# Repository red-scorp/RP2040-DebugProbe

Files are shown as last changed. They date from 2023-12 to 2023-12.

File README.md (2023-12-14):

```
____________  _____  _____    ___ _____                
| ___ \ ___ \/ __  \|  _  |  /   |  _  |               
| |_/ / |_/ /`' / /'| |/' | / /| | |/' |               
|    /|  __/   / /  |  /| |/ /_| |  /| |               
| |\ \| |    ./ /___\ |_/ /\___  \ |_/ /               
\_| \_\_|    \_____/ \___/     |_/\___/                
______     _                ______          _          
|  _  \   | |               | ___ \        | |         
| | | |___| |__  _   _  __ _| |_/ / __ ___ | |__   ___ 
| | | / _ \ '_ \| | | |/ _` |  __/ '__/ _ \| '_ \ / _ \
| |/ /  __/ |_) | |_| | (_| | |  | | | (_) | |_) |  __/
|___/ \___|_.__/ \__,_|\__, \_|  |_|  \___/|_.__/ \___|
                        __/ |                          
                       |___/                           
```

# RP2040-DebugProbe Project

The **RP2040-DebugProbe** project aims to re-imagine Raspberry Pi Debug Probe.

## RP2040-DebugProbe Board

The **RP2040-DebugProbe** board is a 4-layer design intended to accommodate the popular Raspberry Pi RP2040 MCU with all required component to function identically to Raspberry Pi Debug Probe.

This board features target JTAG connector and PC host USB Type-C connector. It also has a SWD connector and UART connector for the main MCU debugging. The board is pin-compatible with Raspberry Pi Debug Probe and can be used with the same picoprobe SW.

Preview:

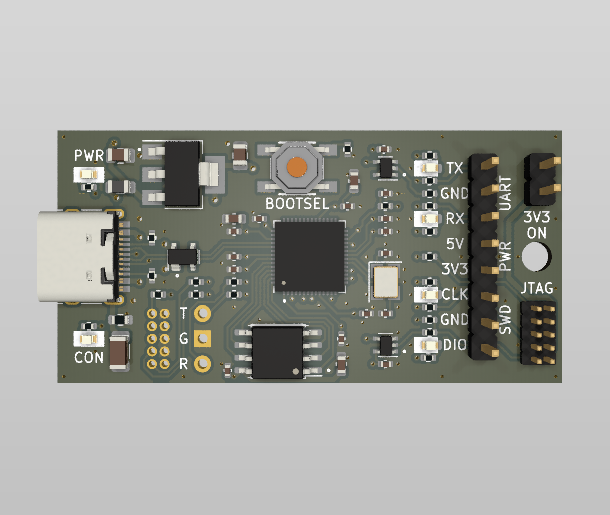
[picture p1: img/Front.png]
RP2040-DebugProbe Front preview

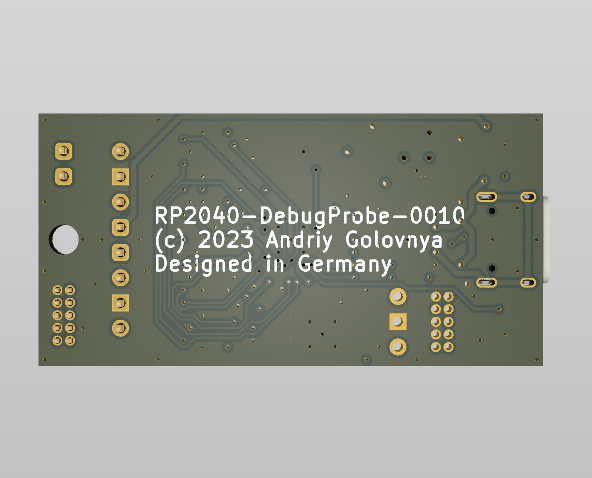
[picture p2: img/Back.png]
RP2040-DebugProbe Back preview

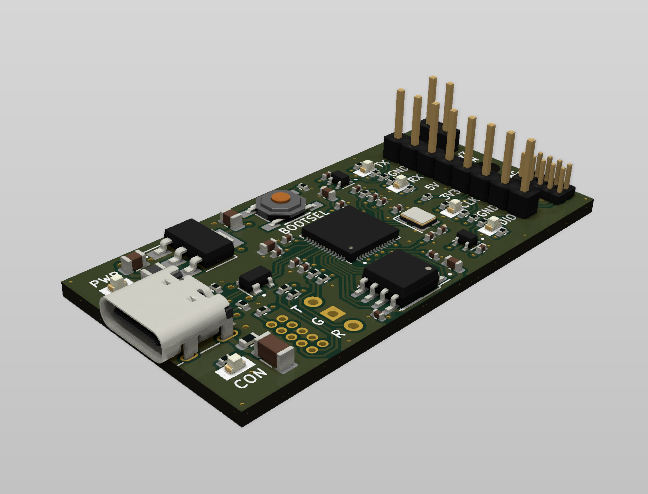
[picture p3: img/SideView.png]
RP2040-DebugProbe Side View preview


You can view the [Schematics in PDF format](doc/RP2040-DebugProbe.pdf) for detailed information.

STEP 3D file is available [with pins](doc/RP2040-DebugProbe.step).

Features:

- Very small form-factor of about 50x25mm (2x1in).
- Raspberry Pi RP2040 MCU as a heart of the board.
- 2x5 1.27mm JTAG connector for programming and debugging.
- 1x8 2.54mm SWD/UART/Power connector for programming and debugging.
- USB Type-C connector for power and communication.
- Several LEDs to indicate power and status.
- 2x5 1.27mm SWD connector and 1x3 2.54mm UART connector for main MCU debugging.
- BOOTSEL button to enter the bootloader mode for flashing new picoprobe SW.
- Pin-compatible with Raspberry Pi Debug Probe.
- Extra TARGET_RESET line connected to GPIO10 for target MCU reset over JTAG.

CAM files, as well as the BOM and CPL files for JLCPCB, are available.

## Version History

### v1.0b1

v1.0b1 board preview

Initial release for testing purposes.

## Links

- [Raspberry Pi RP2040 information page](https://www.raspberrypi.com/documentation/microcontrollers/rp2040.html).
- [Raspberry Pi Debug Probe information page](https://www.raspberrypi.com/documentation/microcontrollers/debug-probe.html).
- [Picoprobe SW for the board](https://github.com/raspberrypi/picoprobe).

## How to Help

Your contributions as code, resources, or finances are welcome! Please contact me directly via email at andriy.golovnya@gmail.com or through my [GitHub profile](https://github.com/red-scorp).

If you'd like to make a financial contribution, you can donate via [PayPal](http://paypal.me/redscorp) or [Ko-Fi](http://ko-fi.com/redscorp). Your support is greatly appreciated.

Thanks in advance!

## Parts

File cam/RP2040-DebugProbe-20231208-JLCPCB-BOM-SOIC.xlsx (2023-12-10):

Qty | Designator | Footprint | JLCPCB Part# | Comment
12 | R13,R19,R23,R15,R16,R22,R18,R17,R21,R9,R20,R14 | 0402 | C25076 | 100R
2 | D7,D4 | 0603 | C72038 | YELLOW
13 | C4,C11,C9,C3,C17,C7,C12,C13,C18,C2,C6,C10,C8 | 0402 | C1525 | 100nF
3 | C5,C1,C16 | 0603 | C1604 | 2.2uF
1 | FB2 | 0805 | C1015 | GZ2012D101TF
2 | U3,U6 | SC-70-5 | C2652100 | 74AUP1T17
2 | D2,D5 | 0603 | C2286 | RED
2 | R11,R10 | 0402 | C25905 | 5k1
1 | J1 | SMD,P=1.27mm | C2935953 | CONN_MCU_JTAG
2 | C20,C19 | 0402 | C1547 | 12pF
1 | U2 | LQFN-56(7x7) | C2040 | RP2040
7 | R3,R7,R5,R1,R6,R4,R2 | 0402 | C11702 | 1k
1 | J4 | Plugin,P=2.54mm | C2685154 | CONN_3V3_JUMPER
1 | C21 | 1206 | C106074 | 4.7nF 1kV
2 | C14,C15 | 0805 | C15850 | 10uF
1 | J7 | SMD,P=1.27mm | C2935953 | CONN_DBG_JTAG
1 | D3 | SOT-143 | C5158049 | PRTR5V0U2X
1 | SW1 | SMD | C318884 | TS-1187A-B-A-B
2 | D1,D6 | 0603 | C72043 | GREEN
1 | J10 | SMD | C2689844 | CONN_USB
1 | Y1 | SMD3225-4P | C9002 | 12MHz
1 | U1 | SOIC-8-208mil | C97521 | W25Q128JVS
1 | U5 | SOT-223 | C6187 | AMS1117-3.3
1 | J3 | Plugin,P=2.54mm | C6332201 | CONN_DBG_COMB
1 | J2 | Plugin,P=2.54mm | C429954 | CONN_MCU_UART
1 | R8 | 0402 | C25744 | 10k
1 | R12 | 0603 | C136593 | 1M

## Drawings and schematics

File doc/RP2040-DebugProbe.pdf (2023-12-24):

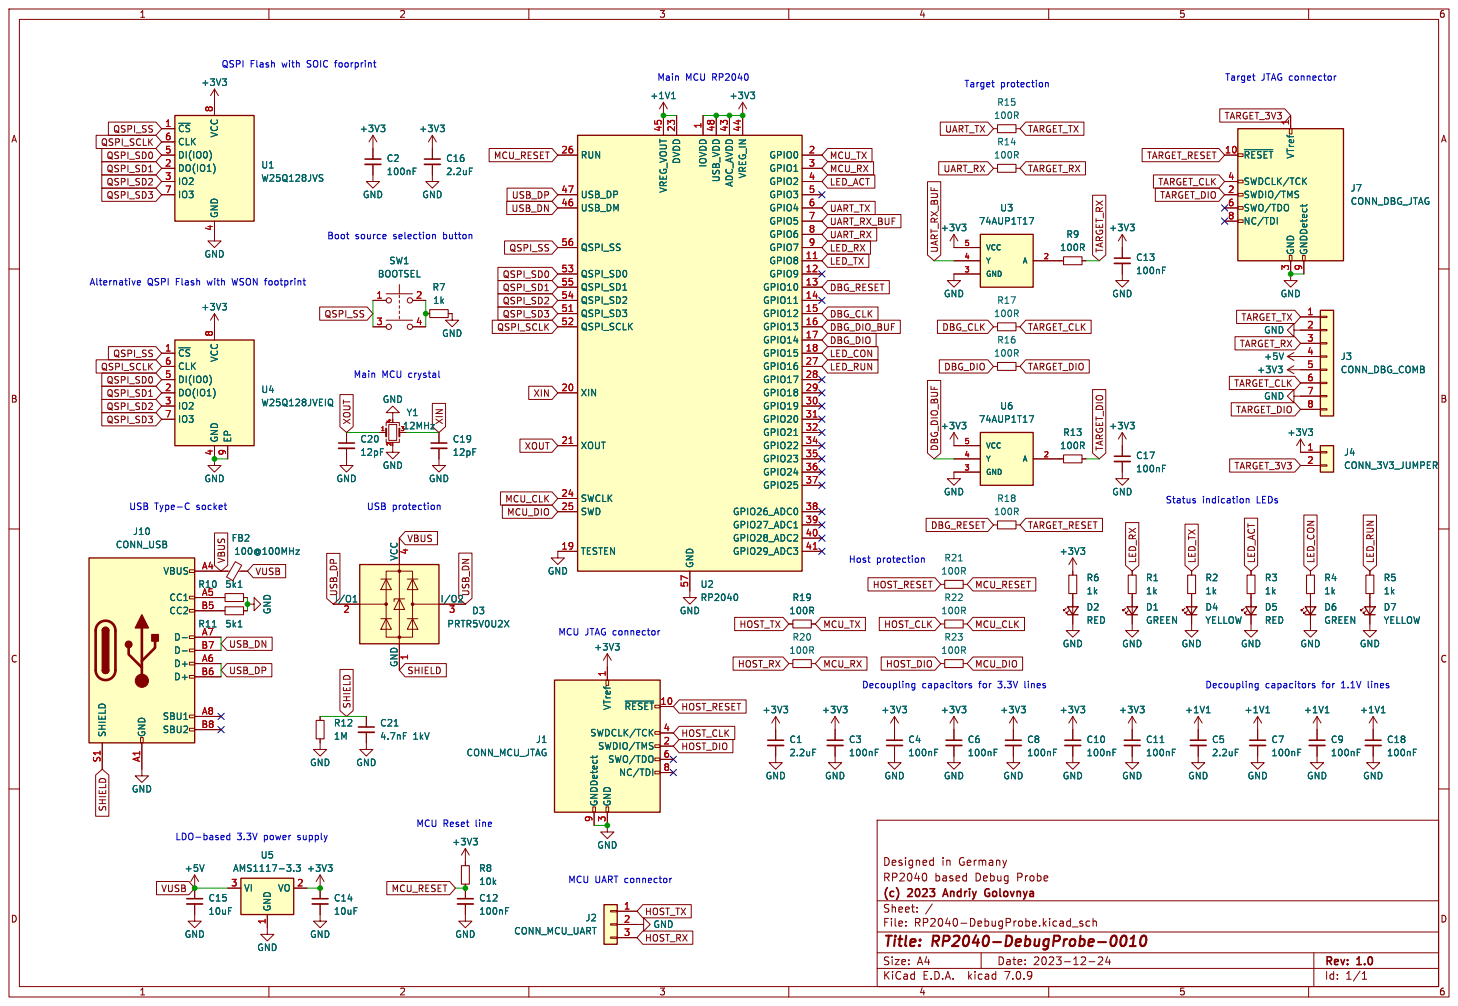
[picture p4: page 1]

1 GPIO8 11 GPIO9 12 GPIO10 13 GPIO11 14 GPIO12 15 GPIO13 16 GPIO14 17 GPIO15 18 TESTEN 19 GPIO0 2 XIN 20 XOUT 21 DVDD 23 SWCLK 24 SWD 25 RUN 26 GPIO16 27 GPIO17 28 GPIO18 29 GPIO1 3 GPIO19 30 GPIO20 31 GPIO21 32 GPIO22 34 GPIO23 35 GPIO24 36 GPIO25 37 GPIO26_ADC0 38 GPIO27_ADC1 39 GPIO2 4 GPIO28_ADC2 40 GPIO29_ADC3 41 ADC_AVDD 43 VREG_IN 44 VREG_VOUT 45 USB_DM 46 USB_DP 47 USB_VDD 48 GPIO3 5 QSPI_SD3 51 QSPI_SCLK 52 QSPI_SD0 53 QSPI_SD2 54 QSPI_SD1 55 QSPI_SS 56 GND 57 GPIO4 6 GPIO5 7 GPIO6 8 GPIO7 9 GND GND GND

1 GPIO8 11 GPIO9 12 GPIO10 13 GPIO11 14 GPIO12 15 GPIO13 16 GPIO14 17 GPIO15 18 TESTEN 19 GPIO0 2 XIN 20 XOUT 21 DVDD 23 SWCLK 24 SWD 25 RUN 26 GPIO16 27 GPIO17 28 GPIO18 29 GPIO1 3 GPIO19 30 GPIO20 31 GPIO21 32 GPIO22 34 GPIO23 35 GPIO24 36 GPIO25 37 GPIO26_ADC0 38 GPIO27_ADC1 39 GPIO2 4 GPIO28_ADC2 40 GPIO29_ADC3 41 ADC_AVDD 43 VREG_IN 44 VREG_VOUT 45 USB_DM 46 USB_DP 47 USB_VDD 48 GPIO3 5 QSPI_SD3 51 QSPI_SCLK 52 QSPI_SD0 53 QSPI_SD2 54 QSPI_SD1 55 QSPI_SS 56 GND 57 GPIO4 6 GPIO5 7 GPIO6 8 GPIO7 9 U2 RP2040 R9

3 SWDCLK/TCK 4 SWO/TDO 6 NC/TDI 8 GNDDetect 9

3 SWDCLK/TCK 4 SWO/TDO 6 NC/TDI 8 GNDDetect 9 GND

3 SWDCLK/TCK 4 SWO/TDO 6 NC/TDI 8 GNDDetect 9 GND J2 CONN_MCU_UART

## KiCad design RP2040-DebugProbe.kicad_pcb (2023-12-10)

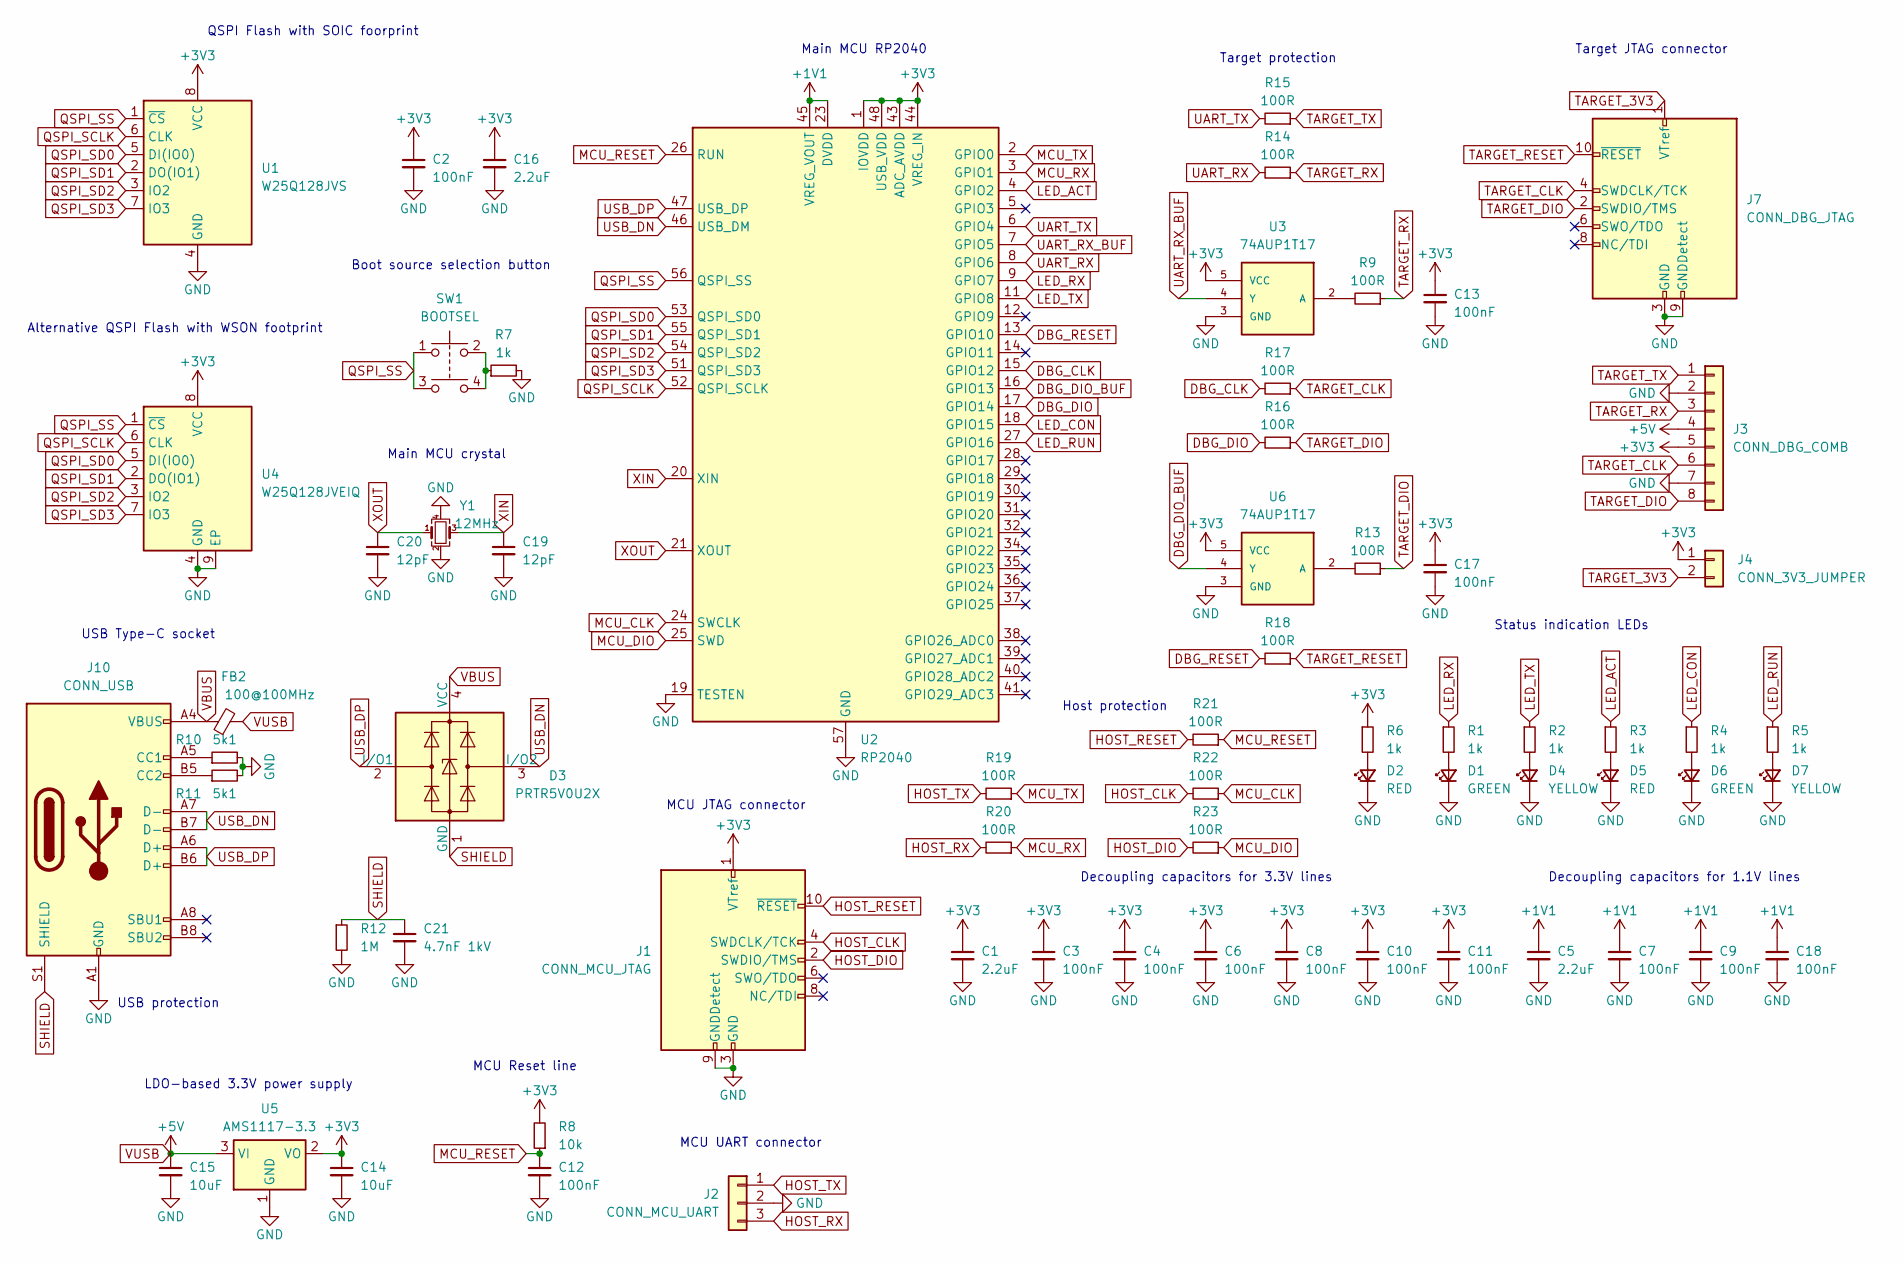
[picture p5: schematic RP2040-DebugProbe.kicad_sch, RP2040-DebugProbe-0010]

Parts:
C1, C5, C16: 2.2uF; C_0603_1608Metric
C2, C3, C4, C6, C7, C8, C9, C10, C11, C12, C13, C17, C18: 100nF; C_0402_1005Metric
C14, C15: 10uF; C_0805_2012Metric
C19, C20: 12pF; C_0402_1005Metric
C21: 4.7nF 1kV; C_1206_3216Metric
D1, D6: GREEN; LED_0603_1608Metric
D2, D5: RED; LED_0603_1608Metric
D3: PRTR5V0U2X; SOT-143
D4, D7: YELLOW; LED_0603_1608Metric
FB2: 100@100MHz; L_0805_2012Metric
J1: CONN_MCU_JTAG; PinHeader_2x05_P1.27mm_Vertical
J2: CONN_MCU_UART; PinHeader_1x03_P2.54mm_Vertical
J3: CONN_DBG_COMB; PinHeader_1x08_P2.54mm_Vertical
J4: CONN_3V3_JUMPER; PinHeader_1x02_P2.54mm_Vertical
J7: CONN_DBG_JTAG; PinHeader_2x05_P1.27mm_Vertical
J10: CONN_USB; USB_C_Receptacle_HRO_TYPE-C-31-M-12
R1, R2, R3, R4, R5, R6, R7: 1k; R_0402_1005Metric
R8: 10k; R_0402_1005Metric
R9, R13, R14, R15, R16, R17, R18, R19, R20, R21, R22, R23: 100R; R_0402_1005Metric
R10, R11: 5k1; R_0402_1005Metric
R12: 1M; R_0603_1608Metric
SW1: BOOTSEL; Button_Tact_Sqkg
U1: W25Q128JVS; SOIC-8_5.23x5.23mm_P1.27mm
U2: RP2040; QFN-56-1EP_7x7mm_P0.4mm_EP3.2x3.2mm
U3, U6: 74AUP1T17; SOT-353_SC-70-5
U4: W25Q128JVEIQ; WSON-8-1EP_6x5mm_P1.27mm_EP3.4x4.3mm
U5: AMS1117-3.3; SOT-223-3_TabPin2
Y1: 12MHz; Crystal_SMD_3225-4Pin_3.2x2.5mm

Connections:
+1V1: C5.1, C7.1, C9.1, C18.1, U2.23 (DVDD), U2.45 (VREG_VOUT), U2.50 (DVDD)
+3V3: C1.1, C2.1, C3.1, C4.1, C6.1, C8.1, C10.1, C11.1, C13.1, C14.1, C16.1, C17.1, J1.1 (VTref), J3.5, J4.1, R6.1, R8.2, U1.8 (VCC), U2.1 (IOVDD), U2.10 (IOVDD), U2.22 (IOVDD), U2.33 (IOVDD), U2.42 (IOVDD), U2.43 (ADC_AVDD), U2.44 (VREG_IN), U2.48 (USB_VDD), U2.49 (IOVDD), U3.5 (VCC), U4.8 (VCC), U5.2 (VO), U6.5 (VCC)
DBG_CLK: R17.2, U2.15 (GPIO12)
DBG_DIO: R16.2, U2.17 (GPIO14)
DBG_DIO_BUF: U2.16 (GPIO13), U6.4 (Y)
DBG_RESET: R18.2, U2.13 (GPIO10)
GND: C1.2, C2.2, C3.2, C4.2, C5.2, C6.2, C7.2, C8.2, C9.2, C10.2, C11.2, C12.2, C13.2, C14.2, C15.2, C16.2, C17.2, C18.2, C19.2, C20.2, C21.2, D1.1 (K), D2.1 (K), D4.1 (K), D5.1 (K), D6.1 (K), D7.1 (K), J1.3 (GND), J1.5 (GND), J1.9 (GNDDetect), J2.2, J3.2, J3.7, J7.3 (GND), J7.5 (GND), J7.9 (GNDDetect), J10.A1 (GND), J10.A12 (GND), J10.B1 (GND), J10.B12 (GND), R7.2, R10.2, R11.2, R12.2, U1.4 (GND), U2.19 (TESTEN), U2.57 (GND), U3.3 (GND), U4.4 (GND), U4.9 (EP), U5.1 (GND), U6.3 (GND), Y1.2, Y1.4
HOST_CLK: J1.4 (SWDCLK/TCK), R22.2
HOST_DIO: J1.2 (SWDIO/TMS), R23.2
HOST_RESET: J1.10 (~RESET), R21.2
HOST_RX: J2.3, R20.2
HOST_TX: J2.1, R19.2
LED_ACT: R3.1, U2.4 (GPIO2)
LED_CON: R4.1, U2.18 (GPIO15)
LED_RUN: R5.1, U2.27 (GPIO16)
LED_RX: R1.1, U2.9 (GPIO7)
LED_TX: R2.1, U2.11 (GPIO8)
MCU_CLK: R22.1, U2.24 (SWCLK)
MCU_DIO: R23.1, U2.25 (SWD)
MCU_RESET: C12.1, R8.1, R21.1, U2.26 (RUN)
MCU_RX: R20.1, U2.3 (GPIO1)
MCU_TX: R19.1, U2.2 (GPIO0)
unnamed: D1.2 (A), R1.2
unnamed: D2.2 (A), R6.2
unnamed: D4.2 (A), R2.2
unnamed: D5.2 (A), R3.2
unnamed: D6.2 (A), R4.2
unnamed: D7.2 (A), R5.2
unnamed: J10.A5 (CC1), R10.1
unnamed: J10.B5 (CC2), R11.1
unnamed: R7.1, SW1.2, SW1.4
unnamed: R9.2, U3.2 (A)
unnamed: R13.2, U6.2 (A)
QSPI_SCLK: U1.6 (CLK), U2.52 (QSPI_SCLK), U4.6 (CLK)
QSPI_SD0: U1.5 (DI(IO0)), U2.53 (QSPI_SD0), U4.5 (DI(IO0))
QSPI_SD1: U1.2 (DO(IO1)), U2.55 (QSPI_SD1), U4.2 (DO(IO1))
QSPI_SD2: U1.3 (IO2), U2.54 (QSPI_SD2), U4.3 (IO2)
QSPI_SD3: U1.7 (IO3), U2.51 (QSPI_SD3), U4.7 (IO3)
QSPI_SS: SW1.1, SW1.3, U1.1 (~CS), U2.56 (QSPI_SS), U4.1 (~CS)
SHIELD: C21.1, D3.1 (GND), J10.S1 (SHIELD), R12.1
TARGET_3V3: J4.2, J7.1 (VTref)
TARGET_CLK: J3.6, J7.4 (SWDCLK/TCK), R17.1
TARGET_DIO: J3.8, J7.2 (SWDIO/TMS), R13.1, R16.1
TARGET_RESET: J7.10 (~RESET), R18.1
TARGET_RX: J3.3, R9.1, R14.1
TARGET_TX: J3.1, R15.1
UART_RX: R14.2, U2.8 (GPIO6)
UART_RX_BUF: U2.7 (GPIO5), U3.4 (Y)
UART_TX: R15.2, U2.6 (GPIO4)
USB_DN: D3.3 (I/O2), J10.A7 (D-), J10.B7 (D-), U2.46 (USB_DM)
USB_DP: D3.2 (I/O1), J10.A6 (D+), J10.B6 (D+), U2.47 (USB_DP)
VBUS: D3.4 (VCC), FB2.1, J10.A4 (VBUS), J10.A9 (VBUS), J10.B4 (VBUS), J10.B9 (VBUS)
VUSB: C15.1, FB2.2, J3.4, U5.3 (VI)
XIN: C19.1, U2.20 (XIN), Y1.3
XOUT: C20.1, U2.21 (XOUT), Y1.1

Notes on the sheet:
USB protection
Alternative QSPI Flash with WSON footprint
Main MCU RP2040
Status indication LEDs
MCU JTAG connector
Decoupling capacitors for 3.3V lines
Main MCU crystal
Decoupling capacitors for 1.1V lines
Target protection
Target JTAG connector
USB Type-C socket
Host protection
MCU UART connector
Boot source selection button
LDO-based 3.3V power supply
MCU Reset line
QSPI Flash with SOIC foorprint

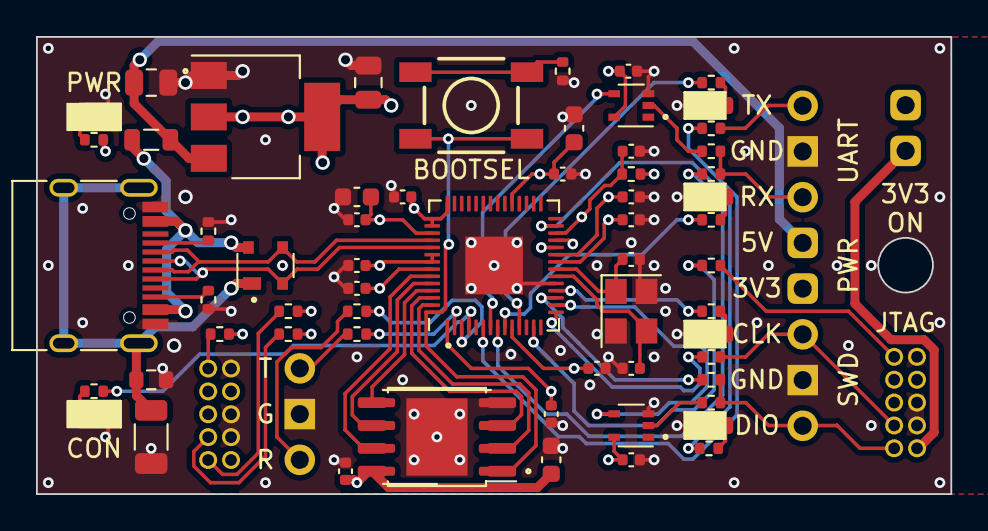
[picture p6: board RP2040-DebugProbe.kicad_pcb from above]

Board: 4 copper layers, 50.8 x 25.4 mm, 66 parts (0 on the bottom side), 55 nets.

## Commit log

2023-12-03 Created base schematics based on current RP2040-Eins board
    [RP2040-DebugProbe.kicad_pcb, RP2040-DebugProbe.kicad_sch]
2023-12-03 Improved schematics
    [RP2040-DebugProbe.kicad_sch]
2023-12-03 Added basic board layout
    [RP2040-DebugProbe.kicad_pcb, RP2040-DebugProbe.kicad_sch]
2023-12-04 Placed components on their approximate locations. Added board approximate outline.
    [RP2040-DebugProbe.kicad_pcb, RP2040-DebugProbe.kicad_sch]
2023-12-04 Moved stuff around
    [RP2040-DebugProbe.kicad_pcb, RP2040-DebugProbe.kicad_sch]
2023-12-05 Added 3D models to the board components
    [RP2040-DebugProbe.kicad_pcb]
2023-12-06 Made the board 4 layer. Made a basic routing.
    [RP2040-DebugProbe.kicad_pcb]
2023-12-07 Generated PDF schematics
2023-12-07 Added target reset line on GPIO 10
    [RP2040-DebugProbe.kicad_pcb, RP2040-DebugProbe.kicad_sch]
2023-12-07 Added host side protection resistors
    [RP2040-DebugProbe.kicad_pcb, RP2040-DebugProbe.kicad_sch]
2023-12-08 Updated file export parameters
    [RP2040-DebugProbe.kicad_pcb]
2023-12-10 Generated generic BOM and CPL files
    [RP2040-DebugProbe-20231208-JLCPCB-BOM.xlsx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]
2023-12-10 Added center lines for connectors
    [RP2040-DebugProbe.kicad_pcb]
2023-12-10 Generated BOM and CPL files
    [RP2040-DebugProbe-20231208-JLCPCB-BOM-SOIC.xlsx, RP2040-DebugProbe-20231208-JLCPCB-BOM-WSON.xlsx, RP2040-DebugProbe-20231208-JLCPCB-BOM.xlsx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]
2023-12-10 Generated STEP 3D model
    [RP2040-DebugProbe.kicad_pcb]
2023-12-24 Moved misplaced label
    [RP2040-DebugProbe.kicad_sch]

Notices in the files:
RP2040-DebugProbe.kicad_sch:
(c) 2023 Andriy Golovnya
